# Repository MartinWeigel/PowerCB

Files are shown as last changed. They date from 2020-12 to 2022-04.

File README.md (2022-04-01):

# PowerCB

PowerCB is a small PCB to power a breadboard with 3.3V. It has a small footprint to avoid blocking pins on the breadboard. The measurements fit an ELEGOO breadboard, but should work with other brands as well. It can be either used on the side of the breadboard to power one side only *or* in the middle to bridge all power lines. The board can be powered through USB-C or the two mounting holes, e.g. by connecting it to a power supply. It is based on a [TPS73633](http://www.ti.com/product/TPS73633-EP) low-dropout (LDO) linear voltage regulator. The optional 0805-capacitor pads can be used for additional bypass capacitors.

This board was designed using [KiCad 6.0](http://www.kicad.org).

## Design
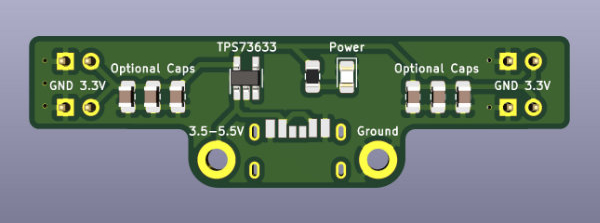
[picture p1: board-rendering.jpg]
Rendering of the board

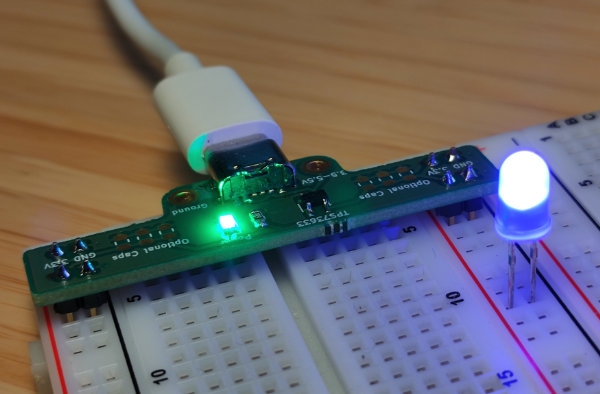
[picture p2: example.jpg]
Example usage of the board


## BOM
Reference | Part        | Description
--------- | ----------- | ---
U1        | <a href="https://www.mouser.de/ProductDetail/595-TPS73633DBVR/">TPS73633DBVR</a> | 3.3V LDO Voltage Regulator
U2        | <a href="https://www.mouser.de/ProductDetail/CUI-Devices/UJC-HP-3-SMT-TR?qs=vmHwEFxEFR%252BLRSV%252Bufrn1g%3D%3D">UJC-HP-3-SMT-TR</a> | USB Type C receptacle
R1        | 0805 Resistor     | Resistor for LED (680 Ω)
R2        | 0805 Resistor     | USB-C pulldown resistor (5.1 kΩ)
R3        | 0805 Resistor     | USB-C pulldown resistor (5.1 kΩ)
D1        | 0805 LED          | Power-on status
C1-6      | 0805 Capacitor    | Optional capacitors
J6-9      | Male Pin Header   | 2.54mm spacing

## License
<br />This work is licensed under a <a rel="license" href="http://creativecommons.org/licenses/by/4.0/">Creative Commons Attribution 4.0 International License</a>.

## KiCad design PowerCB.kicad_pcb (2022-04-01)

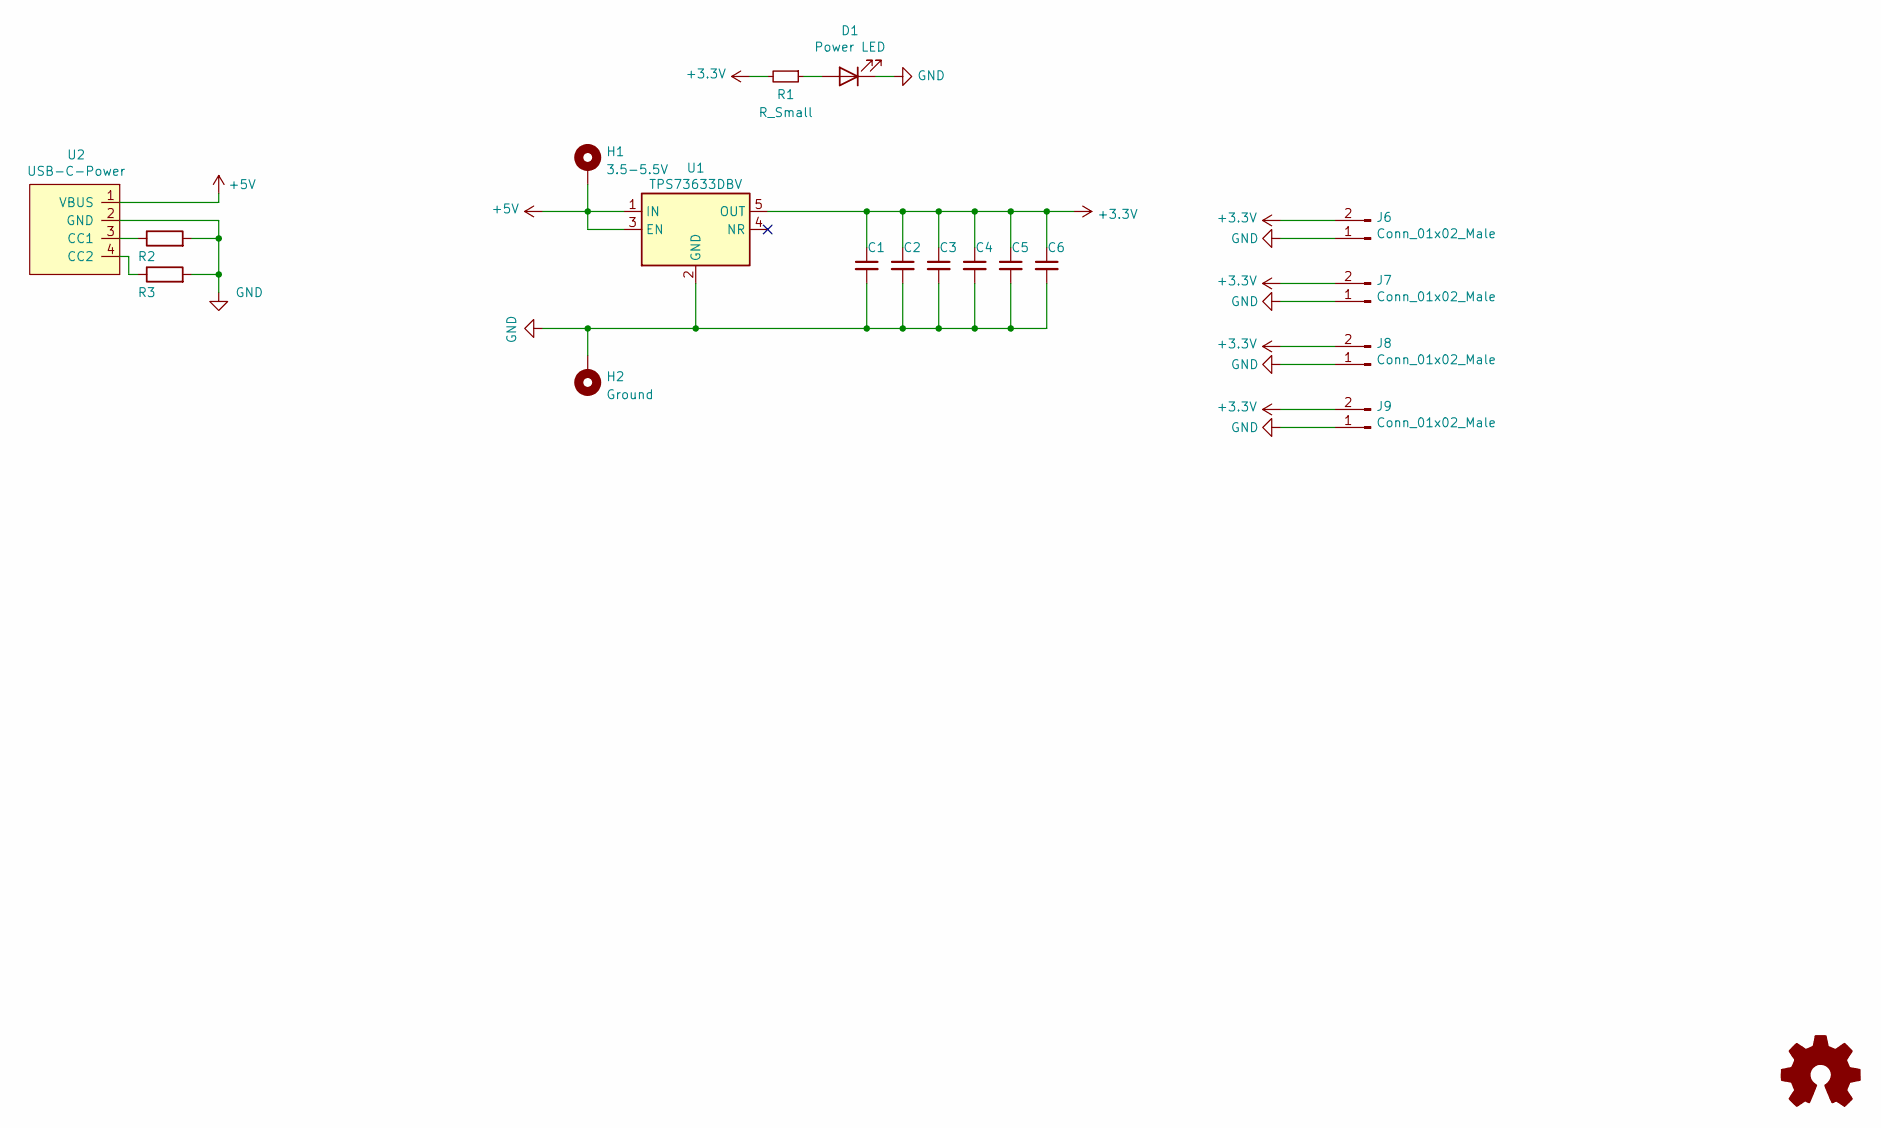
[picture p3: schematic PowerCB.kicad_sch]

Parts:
C1, C2, C3, C4, C5, C6: C_Small; C_0805_2012Metric_Pad1.15x1.40mm_HandSolder
D1: Power LED; LED_0805_2012Metric_Pad1.15x1.40mm_HandSolder
H1: 3.5-5.5V; MountingHole_3.2mm_M3_DIN965_Pad
H2: Ground; MountingHole_3.2mm_M3_DIN965_Pad
J6, J7, J8, J9: Conn_01x02_Male; PinHeader_1x02_P2.54mm_Vertical
R1: R_Small; R_0805_2012Metric_Pad1.15x1.40mm_HandSolder
R2, R3: (no value)
U1: TPS73633DBV; SOT-23-5_HandSoldering
U2: USB-C-Power; UJC-HP-3-SMT-TR

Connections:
+3V3: C1.1, C2.1, C3.1, C4.1, C5.1, C6.1, J6.2, J7.2, J8.2, J9.2, R1.2, U1.5 (OUT)
+5V: H1.1, U1.1 (IN), U1.3 (EN), U2.1 (VBUS)
GND: C1.2, C2.2, C3.2, C4.2, C5.2, C6.2, D1.1 (K), H2.1, J6.1, J7.1, J8.1, J9.1, R2.2, R3.2, U1.2 (GND), U2.2 (GND)
unnamed: D1.2 (A), R1.1
unnamed: R2.1, U2.3 (CC1)
unnamed: R3.1, U2.4 (CC2)

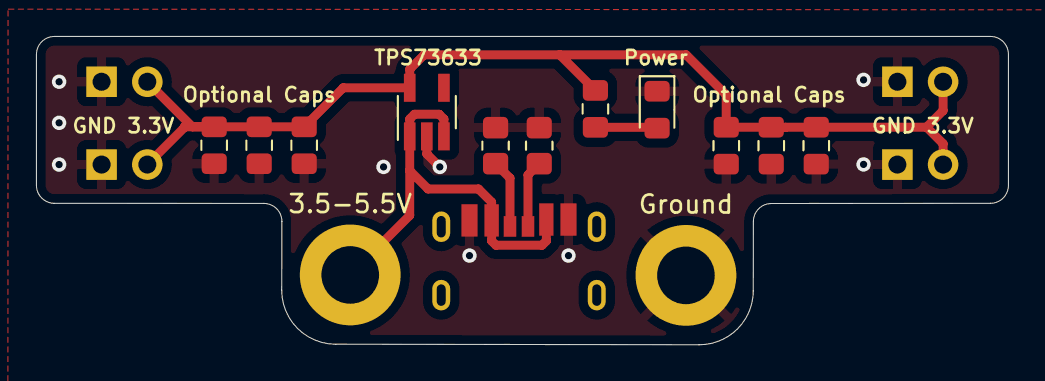
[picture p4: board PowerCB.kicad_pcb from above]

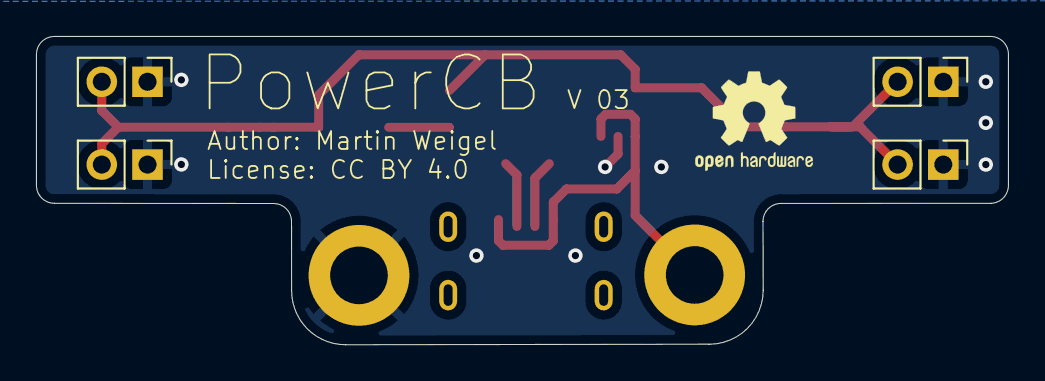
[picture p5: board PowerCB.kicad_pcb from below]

Board: 2 copper layers, 54.0 x 17.1 mm, 18 parts (4 on the bottom side), 6 nets.

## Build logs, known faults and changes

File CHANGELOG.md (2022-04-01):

# Changelog

## v03
- Add pulldown resistor for USB-C (CC pins)
- Use M3 mounting holes instead of M2
- File formats for KiCad 6.0
- Add OSHW logo

## v02
- USB-C instead of micro-USB connector

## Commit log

2019-12-14 PowerCB V01
    [PowerCB.kicad_pcb, PowerCB.sch]
2020-12-21 feat: USB-C instead of Micro-USB connector
    [PowerCB.kicad_pcb, PowerCB.sch]
2022-03-26 chore: convert to KiCad 6 file formats
    [PowerCB.kicad_pcb, PowerCB.kicad_sch, PowerCB.sch]
2022-03-26 feat: M3 instead of M2 mounting holes
    [PowerCB.kicad_pcb, PowerCB.kicad_sch]
2022-04-01 fix: missing USB-C CC pulldown resistors
    [PowerCB.kicad_pcb, PowerCB.kicad_sch]
2022-04-01 feat: OSHW logo
    [PowerCB.kicad_pcb]

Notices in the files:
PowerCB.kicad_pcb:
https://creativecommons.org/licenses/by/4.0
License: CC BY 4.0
